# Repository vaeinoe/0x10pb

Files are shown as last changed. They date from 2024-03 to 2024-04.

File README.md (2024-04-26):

# 0x10pb

0x10pb

## What?

Yet another MIDI CC controller in 200x75mm footprint. 16 potentiometers x 4 banks. USB-C for flashing and MIDI device communication, hardware TRS MIDI type A output. Option for battery power.

MIDI CCs, channels and scaling per knob for all the four banks are programmable in the firmware (not on the fly via SysEx, at least not yet). Sends identical messages via both USB and TRS.

## Why?

There are many small DIY MIDI controllers more refined than this one, but I wanted something to use with battery-powered portable electronic instruments like the Dirtywave M8 and Teenage Engineering OP-1 Field, and

 1. I couldn't find anything that was battery powered and with both USB and hardware serial MIDI output. It's kind of a letdown to have a portable instrument with an internal battery and then have to carry around a power bank just for an auxiliary controller. Especially as most of these instruments don't act as USB hosts so you can't even power controllers directly from them.
 2. Most of the simple controllers are missing any kind of bank / page system. Quite often you want to control more than 16 parameters without remapping, but don't need to control them all at the same time.

Then a friend wanted one like this too for similar reasons, so I had to actually design one.

## How?

There's not much to it. A custom carrier board with a power switch, a bank button, two LEDs that indicate which bank is active (00, 01, 10, 11), TRS MIDI port and associated circuitry, and 16 pots read via a single multiplexer.

[Adafruit Feather RP2040](https://learn.adafruit.com/adafruit-feather-rp2040-pico) is used as the brain. Mainly because it conveniently has both a USB-C port and battery power / charging circuit built in.

### Hardware

First you'll need to get a carrier PCB. KiCad project and Gerbers are included for ordering your own. Once you have that, here's a list of parts you'll need to populate the board:

 - Adafruit Feather RP2040 plus suitable headers (eg. Adafruit slim ones): PCB will likely work with almost any Feather but you may need to modify pin mapping and use a different core lib
 - Optional: 3.7V LiPoly battery with Feather compatible (JST-PH) connector - I use a tiny 500mA one
 - U1: CD74HC4067M (SOIC)
 - U2: 74LVC1G07 (SOT-23-5 / SOT-25)
 - D1-D2: 3mm LED (Whichever you want, I used low power green ones)
 - J3: CUI SJ1-3523N TRS jack
 - C1-C2: 100nF 0603 capacitors
 - R1: 30R 0603 resistor
 - R2: 10R 0603 resistor
 - R3: 10k 0603 resistor
 - R4-R5: 0603 LED series resistors - calculate for your LEDs and 3.3V supply voltage, I used 330R
 - SW1: SPST Subminiature switch (5mm leg spacing)
 - SW2: Omron B3F-10xx series tactile switch + cap
 - RV1-RV16: 10k standard 9mm footprint potentiometers, eg. Alpha 9mm, plus relatively slim knobs such as Davies 1900h clones

If you can (hand) solder SOIC and 0603, populating the board is going to be fast and straightforward. Just mind the build order - SMT components first, and if you don't use removable headers for the Feather you might want to solder the pots before that so the Feather won't get in the way. Oh, and mind the SPST power switch polarity if you actually want "power off" to be on the left and "power on" on the right...

The repository includes a simple "sandwich" type panel design. If you use that, you'll also need some M3 spacers and screws. The exact height will depend on eg. how you mount the Feather. Try eg. 6x 10-12mm male-female ones for the front side (just attaching the panel using pots and power switch is OK too), 6x 17-18mm female-female ones for the back, plus 12x short screws to put it together. 

If you use removable header stack for the Feather, you may also want to secure the board in place with a short M2.5 spacer / screw and nut. Otherwise it may slip off during weeks / months / years of use.

For keeping the battery in place, use something like 3M Dual Lock or generic velcro to attach it to the bottom of the PCB or bottom panel. That way you can actually remove and replace the battery if you need to, but it won't move around.

### Firmware + bank mappings

Firmware can be edited and flashed with [Arduino IDE](https://www.arduino.cc/en/software). You'll also need to install these libraries (see instructions in respective repositories):

 - Earle F. Philhower, III's [Raspberry Pi Pico Arduino core](https://github.com/earlephilhower/arduino-pico)
 - Forty Seven Effects' [Arduino MIDI library](https://github.com/FortySevenEffects/arduino_midi_library)

After you have the IDE and the libraries installed, open the included Arduino sketch. In Tools menu, select "Adafruit Feather RP2040" as the board and "Adafruit TinyUSB" as the USB stack. Other options can be left as is. Then attach the USB-C cable to the Feather and turn power on. You should now be able to upload the sketch to the Feather via USB.

If the device isn't automatically recognized and you get an upload error, you may have to keep the "bootsel" button (in the back end of the board) pressed, quickly press "reset" towards the front of the board and finally release "bootsel" to get the board to bootloader mode. Then try uploading again.

The sketch also includes the hardcoded MIDI CC mappings for all the four banks. For now, whenever you want to edit the mappings, edit the source file according to instructions in the comments, then upload a new version to the Feather.

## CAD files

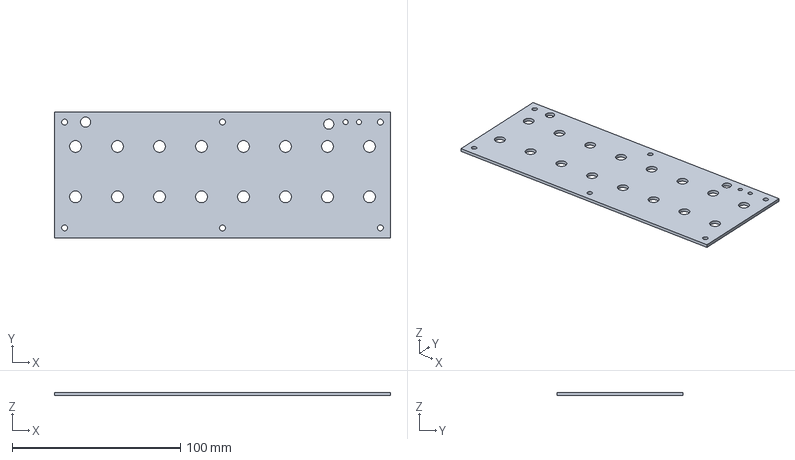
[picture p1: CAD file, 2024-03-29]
panel/0x10pb-front.stp
200.0 x 75.0 x 2.00 mm

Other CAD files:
panel/0x10pb-back.stp

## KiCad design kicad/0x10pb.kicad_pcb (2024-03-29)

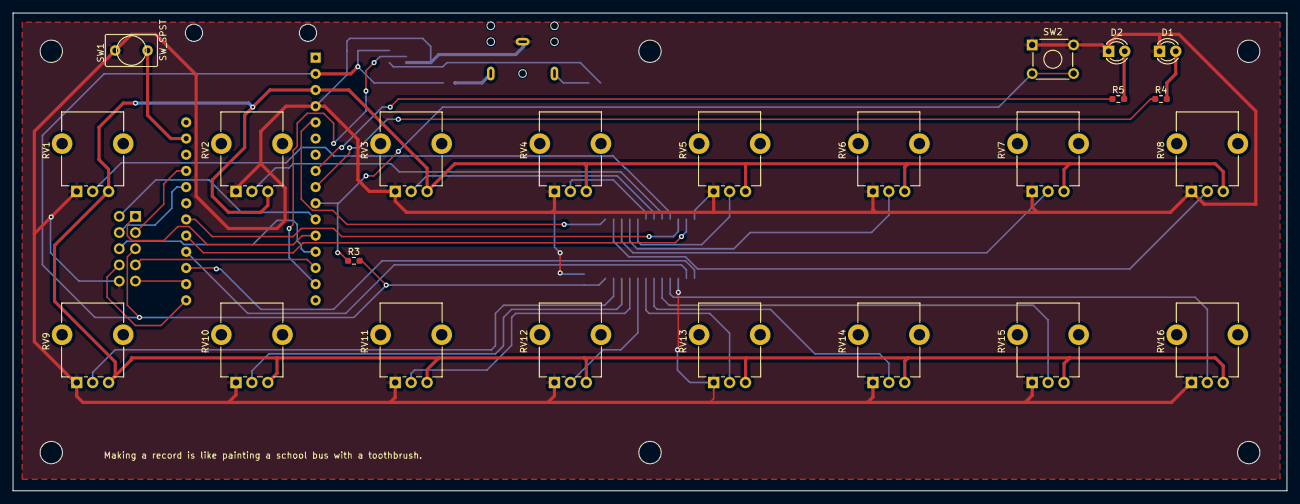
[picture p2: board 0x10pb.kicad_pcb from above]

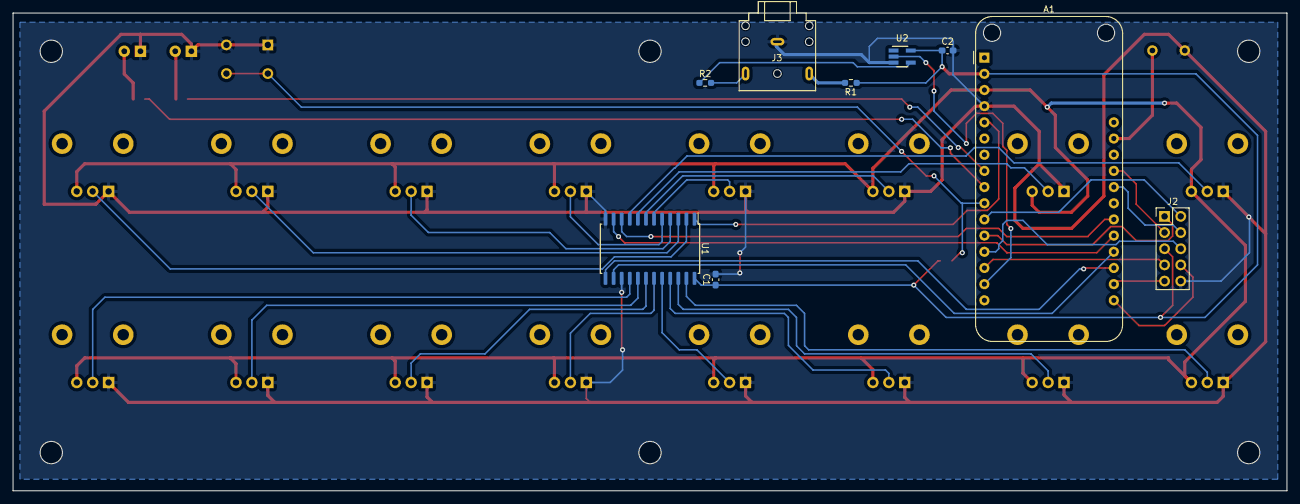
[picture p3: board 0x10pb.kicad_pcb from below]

Board: 2 copper layers, 200.0 x 75.0 mm, 32 parts (9 on the bottom side), 42 nets.

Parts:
A1: Adafruit_Feather_Generic; Adafruit_Feather
C1, C2: 100nF; C_0603_1608Metric_Pad1.08x0.95mm_HandSolder
D1, D2: LED; LED_D3.0mm
J2: Conn_02x05_Top_Bottom; PinHeader_2x05_P2.54mm_Vertical
J3: AudioJack3; Jack_3.5mm_CUI_SJ1-3523N_Horizontal
R1: 30R; R_0603_1608Metric_Pad0.98x0.95mm_HandSolder
R2: 10R; R_0603_1608Metric_Pad0.98x0.95mm_HandSolder
R3: 10k; R_0603_1608Metric_Pad0.98x0.95mm_HandSolder
R4, R5: 68R; R_0603_1608Metric_Pad0.98x0.95mm_HandSolder
RV1, RV2, RV3, RV4, RV5, RV6, RV7, RV8, RV9, RV10, RV11, RV12, RV13, RV14, RV15, RV16: R_Potentiometer; Potentiometer_Alpha_RD901F-40-00D_Single_Vertical_CircularH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
SW1: SW_SPST; Switch_Toggle_SPST_SubMini
SW2: SW_Push; SW_TH_Tactile_Omron_B3F-10xx
U1: CD74HC4067M; SOIC-24W_7.5x15.4mm_P1.27mm
U2: 74LVC1G07; SOT-23-5_HandSoldering

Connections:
+3.3V: A1.2 (3V3), C1.1, C2.1, J2.5, R1.1, R3.2, U1.24 (VCC), U2.5 (VCC)
+3.3VA: A1.3 (AREF), RV1.3, RV2.3, RV3.3, RV4.3, RV5.3, RV6.3, RV7.3, RV8.3, RV9.3, RV10.3, RV11.3, RV12.3, RV13.3, RV14.3, RV15.3, RV16.3
GND: A1.4 (GND), C1.2, C2.2, D1.1 (K), D2.1 (K), J2.10, J3.S, RV1.1, RV2.1, RV3.1, RV4.1, RV5.1, RV6.1, RV7.1, RV8.1, RV9.1, RV10.1, RV11.1, RV12.1, RV13.1, RV14.1, RV15.1, RV16.1, SW1.1 (A), SW2.1, U1.12 (GND), U1.15 (~E), U2.3 (GND)
unnamed: A1.5 (A0), U1.1 (COM)
unnamed: A1.8 (A3), R5.1
unnamed: A1.9 (A4), R4.1
unnamed: A1.10 (A5), R3.1, SW2.2
unnamed: A1.19 (D0), U1.13 (S3)
unnamed: A1.20 (D1), U1.14 (S2)
unnamed: A1.21 (D2), U1.11 (S1)
unnamed: A1.22 (D3), U1.10 (S0)
unnamed: A1.24 (D5), J2.4
unnamed: A1.25 (D6), J2.3
unnamed: A1.27 (EN), SW1.2 (B)
unnamed: A1.13 (MISO), J2.6
unnamed: A1.12 (MOSI), J2.1
unnamed: A1.14 (RX), J2.7
unnamed: A1.11 (SCK), J2.2
unnamed: A1.18 (SCL), J2.9
unnamed: A1.17 (SDA), J2.8
unnamed: A1.15 (TX), U2.2
unnamed: D1.2 (A), R4.2
unnamed: D2.2 (A), R5.2
unnamed: J3.R, R1.2
unnamed: J3.T, R2.2
unnamed: R2.1, U2.4
unnamed: RV1.2, U1.9 (I0)
unnamed: RV2.2, U1.8 (I1)
unnamed: RV3.2, U1.7 (I2)
unnamed: RV4.2, U1.6 (I3)
unnamed: RV5.2, U1.5 (I4)
unnamed: RV6.2, U1.4 (I5)
unnamed: RV7.2, U1.3 (I6)
unnamed: RV8.2, U1.2 (I7)
unnamed: RV9.2, U1.23 (I8)
unnamed: RV10.2, U1.22 (I9)
unnamed: RV11.2, U1.21 (I10)
unnamed: RV12.2, U1.20 (I11)
unnamed: RV13.2, U1.19 (I12)
unnamed: RV14.2, U1.18 (I13)
unnamed: RV15.2, U1.17 (I14)
unnamed: RV16.2, U1.16 (I15)

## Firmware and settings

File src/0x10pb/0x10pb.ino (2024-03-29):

#ifdef USE_TINYUSB
  #include <Adafruit_TinyUSB.h>
  #include <MIDI.h>
#endif

#define USB_MFG_DESCRIPTOR "Schoolbus                     "
#define USB_PRODUCT_DESCRIPTOR "Schoolbus                     "
#define USB_MIDI_DESCRIPTOR "Schoolbus"

/* Pin mapping for the Adafruit Feather RP2040 and our custom PCB */
#define PIN_LED_1 29
#define PIN_LED_2 24
#define PIN_MUX_0 10
#define PIN_MUX_1 9
#define PIN_MUX_2 8
#define PIN_MUX_3 7
#define PIN_MUX_COM 26
#define PIN_BTN_BANK 25
#define PIN_MIDI_TX 0
#define PIN_MIDI_RX 1

/* You shouldn't need to change these unless you're doing your own board 
   in which case you probably have to rewrite some of the code anyway. */
#define NUM_BANKS 4
#define NUM_POTS 16

/* The analog signals don't quite hit max and min ADC values and there's some jitter
   so limit the actual min and max ADC values, and add some deadbanding + filtering.
   If you encounter issues with dead zones or jitter, try playing with these a bit. */
#define MIN_VAL 4
#define MAX_VAL 1015
#define DEADBAND_VAL 4
#define MOVING_AVG_LENGTH 32

Adafruit_USBD_MIDI usbMidi;
MIDI_CREATE_INSTANCE(Adafruit_USBD_MIDI, usbMidi, usbMidiDevice);
MIDI_CREATE_INSTANCE(HardwareSerial, Serial1, serialMidiDevice);

/* Change these to adjust the banks to your liking, then (re)upload. 
   The groups of 16 are individual banks, in format 
   {midiChannel, ccNumber, minValue, maxValue}. */
int banks[NUM_BANKS][NUM_POTS][4] = {
  {{1, 1, 0, 127},  {1, 2, 0, 127},  {1, 3, 0, 127},  {1, 4, 0, 127},  
   {1, 5, 0, 127},  {1, 6, 0, 127},  {1, 7, 0, 127},  {1, 8, 0, 127}, 
   {1, 9, 0, 127},  {1, 10, 0, 127}, {1, 11, 0, 127}, {1, 12, 0, 127}, 
   {1, 13, 0, 127}, {1, 14, 0, 127}, {1, 15, 0, 127}, {1, 16, 0, 127}},

  {{1, 17, 0, 127}, {1, 18, 0, 127}, {1, 19, 0, 127}, {1, 20, 0, 127},
   {1, 21, 0, 127}, {1, 22, 0, 127}, {1, 23, 0, 127}, {1, 24, 0, 127}, 
   {1, 25, 0, 127}, {1, 26, 0, 127}, {1, 27, 0, 127}, {1, 28, 0, 127}, 
   {1, 29, 0, 127}, {1, 30, 0, 127}, {1, 31, 0, 127}, {1, 32, 0, 127}},

  {{1, 33, 0, 127}, {1, 34, 0, 127}, {1, 35, 0, 127}, {1, 36, 0, 127}, 
   {1, 37, 0, 127}, {1, 38, 0, 127}, {1, 39, 0, 127}, {1, 40, 0, 127}, 
   {1, 41, 0, 127}, {1, 42, 0, 127}, {1, 43, 0, 127}, {1, 44, 0, 127}, 
   {1, 45, 0, 127}, {1, 46, 0, 127}, {1, 47, 0, 127}, {1, 48, 0, 127}},

  {{1, 49, 0, 127}, {1, 50, 0, 127}, {1, 51, 0, 127}, {1, 52, 0, 127}, 
   {1, 53, 0, 127}, {1, 54, 0, 127}, {1, 55, 0, 127}, {1, 56, 0, 127}, 
   {1, 57, 0, 127}, {1, 58, 0, 127}, {1, 59, 0, 127}, {1, 60, 0, 127}, 
   {1, 61, 0, 127}, {1, 62, 0, 127}, {1, 63, 0, 127}, {1, 64, 0, 127}}
};
bool bankChangeRequested = false;
int bank = -1;

/* The pots are hooked up via a single 4067 multiplexer controlled by 4 digital pins */
int muxControlPins[4] = {PIN_MUX_0, PIN_MUX_1, PIN_MUX_2, PIN_MUX_3};
int muxChannels[16][4] = {
  {0,0,0,0}, {1,0,0,0}, {0,1,0,0}, {1,1,0,0}, {0,0,1,0}, {1,0,1,0}, {0,1,1,0}, {1,1,1,0},
  {0,0,0,1}, {1,0,0,1}, {0,1,0,1}, {1,1,0,1}, {0,0,1,1}, {1,0,1,1}, {0,1,1,1}, {1,1,1,1} 
};

/* Keep a moving average over raw values to filter noisy analog signal */
int values[NUM_POTS][MOVING_AVG_LENGTH];
int valueIdx = 0;
bool valuesStable = false;

/* Actual scaled MIDI values, should be only sent when they change */
int midiValues[NUM_POTS];
bool midiValuesChanged[NUM_POTS];
bool midiValuesDirty = false;

void setup() {
  Serial.begin(115200);

  initPins();
  initMidi();
  initValues();

  /* Read a few values until the averages stabilize, so we don't end up
     sending a bunch of unintended CC messages on startup. */
  for (int i = 0; i < 256; i++) {
    readValues();
    updateMidiValues();
  }
  valuesStable = true;

  indicateStartup();
  doBankChange(); // Init to bank 0 so we get proper LED state.
}

void loop() {
  readValues();
  updateMidiValues();
  sendMidiValues();

  if (bankChangeRequested) {
    doBankChange();
  }
}

/* Reads values from multiplexer / analog input to next moving average slot.
   Does some deadbanding to prevent value jitter. */
void readValues() {
  for(int i = 0; i < NUM_POTS; i++) {
    int rawVal = constrain(readMux(i), MIN_VAL, MAX_VAL);
    
    if (rawVal < (values[i][valueIdx] - DEADBAND_VAL) || 
        rawVal > (values[i][valueIdx] + DEADBAND_VAL)) {
      values[i][valueIdx] = rawVal;
    }
  }

  valueIdx = (valueIdx + 1) % MOVING_AVG_LENGTH;
}

/* Sends the changed midi values thru both USB and serial MIDI */
void sendMidiValues() {
  if (!midiValuesDirty) { return; }

  for (int i = 0; i < NUM_POTS; i++) {
    if (midiValuesChanged[i]) {
      int ccNumber = banks[bank][i][1];
      int channel  = banks[bank][i][0];
      int ccValue  = map(midiValues[i], 0, 127, banks[bank][i][2], banks[bank][i][3]);

      usbMidiDevice.sendControlChange(ccNumber, ccValue, channel);
      serialMidiDevice.sendControlChange(ccNumber, ccValue, channel);
      midiValuesChanged[i] = false;
    }
  }
  
  midiValuesDirty = false;
}

/* Once raw values have been read, do some averaging and scale to MIDI CCs.
   If any values have been changed since last write, mark dirty for sending. */
void updateMidiValues() {
  for (int i = 0; i < NUM_POTS; i++) {
    int newVal = 0;
    
    for (int j = 0; j < MOVING_AVG_LENGTH; j++) {
      newVal += values[i][j];
    }
    newVal = map(newVal / MOVING_AVG_LENGTH, MIN_VAL, MAX_VAL, 0, 128);

    int midiVal = constrain(newVal, 0, 127);
    if (midiValues[i] != midiVal) {
      midiValues[i] = midiVal;

      if (valuesStable) {
        midiValuesChanged[i] = true;
        midiValuesDirty = true;
      }
    }
  }
}

int readMux(int channel) {
  for(int i = 0; i < 4; i ++) {
    digitalWrite(muxControlPins[i], muxChannels[channel][i]);
  }
  return analogRead(PIN_MUX_COM);
}

void doBankChange() {
  bank = (bank + 1) % NUM_BANKS;

  // "Binary" LED indicators for the active bank.
  if (bank & 1) { digitalWrite(PIN_LED_2, HIGH); }
  else { digitalWrite(PIN_LED_2, LOW); }

  if (bank & 2) { digitalWrite(PIN_LED_1, HIGH); }
  else { digitalWrite(PIN_LED_1, LOW); }

  bankChangeRequested = false;
}

void initPins() {
  pinMode(PIN_LED_1, OUTPUT);
  pinMode(PIN_LED_2, OUTPUT);
  pinMode(PIN_MUX_0, OUTPUT);
  pinMode(PIN_MUX_1, OUTPUT);
  pinMode(PIN_MUX_2, OUTPUT);
  pinMode(PIN_MUX_3, OUTPUT);
  pinMode(PIN_MUX_COM, INPUT);
  pinMode(PIN_BTN_BANK, INPUT);
  pinMode(PIN_MIDI_TX, OUTPUT);
  pinMode(PIN_MIDI_RX, INPUT);
  attachInterrupt(digitalPinToInterrupt(PIN_BTN_BANK),
                  bankChangeInterrupt,
                  FALLING);
}

void initMidi() {
  Serial1.setTX(PIN_MIDI_TX);
  Serial1.setRX(PIN_MIDI_RX);

  USBDevice.setProductDescriptor(USB_PRODUCT_DESCRIPTOR);
  USBDevice.setManufacturerDescriptor(USB_MFG_DESCRIPTOR);
  usbMidi.setStringDescriptor(USB_MIDI_DESCRIPTOR);

  usbMidiDevice.begin(MIDI_CHANNEL_OMNI);
  serialMidiDevice.begin(MIDI_CHANNEL_OMNI);
}

void initValues() {
  for (int i = 0; i < NUM_POTS; i++) {
    midiValues[i] = 0;
    midiValuesChanged[i] = false;

    for (int j = 0; j < MOVING_AVG_LENGTH; j++) {
      values[i][j] = 0;
    }
  }
}

// Blink LEDs once the init is ready
void indicateStartup() {
  for (int i = 0; i < 3; i++) {
    digitalWrite(PIN_LED_1, HIGH);
    delay(100);
    digitalWrite(PIN_LED_1, LOW);
    delay(100);
    digitalWrite(PIN_LED_2, HIGH);
    delay(100);
    digitalWrite(PIN_LED_2, LOW);
    delay(100);
  }

  Serial.println("0x10pb ready.");
}

void bankChangeInterrupt() {
  bankChangeRequested = true;
}
